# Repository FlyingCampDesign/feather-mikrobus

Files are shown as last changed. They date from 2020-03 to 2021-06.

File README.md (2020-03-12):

# feather-mikrobus
A simple [Adafruit Feather](https://www.adafruit.com/feather) to [mikroBUS](https://www.mikroe.com/mikrobus) socket adapter board.

View this project on [CADLAB.io](https://cadlab.io/project/22579). 

## Hardware

Hardware source files for [KiCad](https://kicad-pcb.org/) are available in the `hardware/` directory.  For details on features and pinouts, see the individual `README.md` for each hardware version.

### Hacking

The KiCad source files depend on the [Flying Camp Design KiCad Library](https://github.com/FlyingCampDesign/fcd-kicad-lib) being available as a git submodule.  The easiest way to ensure that all dependencies are available is to clone this repository using the following command:

```bash
git clone --recurse-submodules https://github.com/FlyingCampDesign/feather-mikrobus.git
```

To ensure that the 3D model paths are configured correctly for the 3D viewer, make sure to follow the FCD library [usage instructions](https://github.com/FlyingCampDesign/fcd-kicad-lib#usage) (otherwise, none of the 3D models will show up).

### [Feather mikroBUS V1](hardware/feather-mikrobus-v1/)

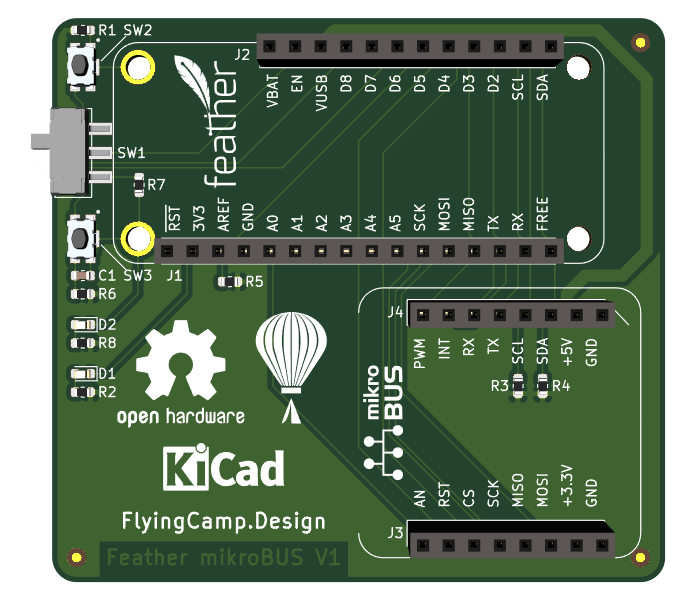
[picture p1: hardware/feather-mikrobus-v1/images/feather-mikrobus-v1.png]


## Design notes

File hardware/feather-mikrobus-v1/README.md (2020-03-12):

# Feather mikroBUS V1



## Features

* Power On/Off switch
* +3.3V power indicator LED
* User button
* User LED
* Bootloader enable (BOOT0) button for [Adafruit Feather STM32F405 Express](https://www.adafruit.com/product/4382)

## Pinout

| Feather Pin Name | mikroBUS Pin Name | FeatherWing Function |
| --- | --- | --- |
| RESET | | (not used) |
| 3V3 | +3.3V | +3.3V |
| AREF | | Connected to +3.3V via 0Ω jumper R5 |
| GND | GND | GND |
| A0 | AN | |
| A1 | | (not used) |
| A2 | | (not used) |
| A3 | | (not used) |
| A4 | | (not used) |
| A5 | | (not used) |
| SCK | SCK | |
| MOSI | MOSI | |
| MISO | MISO | |
| TX | RX | |
| RX | TX | |
| FREE | | Connected to BOOT0 button SW2 for [Adafruit Feather STM32F405 Express](https://www.adafruit.com/product/4382) |
| SCL | SCL | |
| SDA | SDA | |
| D2 | INT | |
| D3 | PWM | |
| D4 | RST | |
| D5 | | Connected to user LED D1 (active low) |
| D6 | | Connected to user button SW3 (active low) |
| D7 | CS | |
| D8 | | (not used) |
| VUSB | +5V | +5V |
| EN | | Controlled by SW1 |
| VBAT | | (not used) |

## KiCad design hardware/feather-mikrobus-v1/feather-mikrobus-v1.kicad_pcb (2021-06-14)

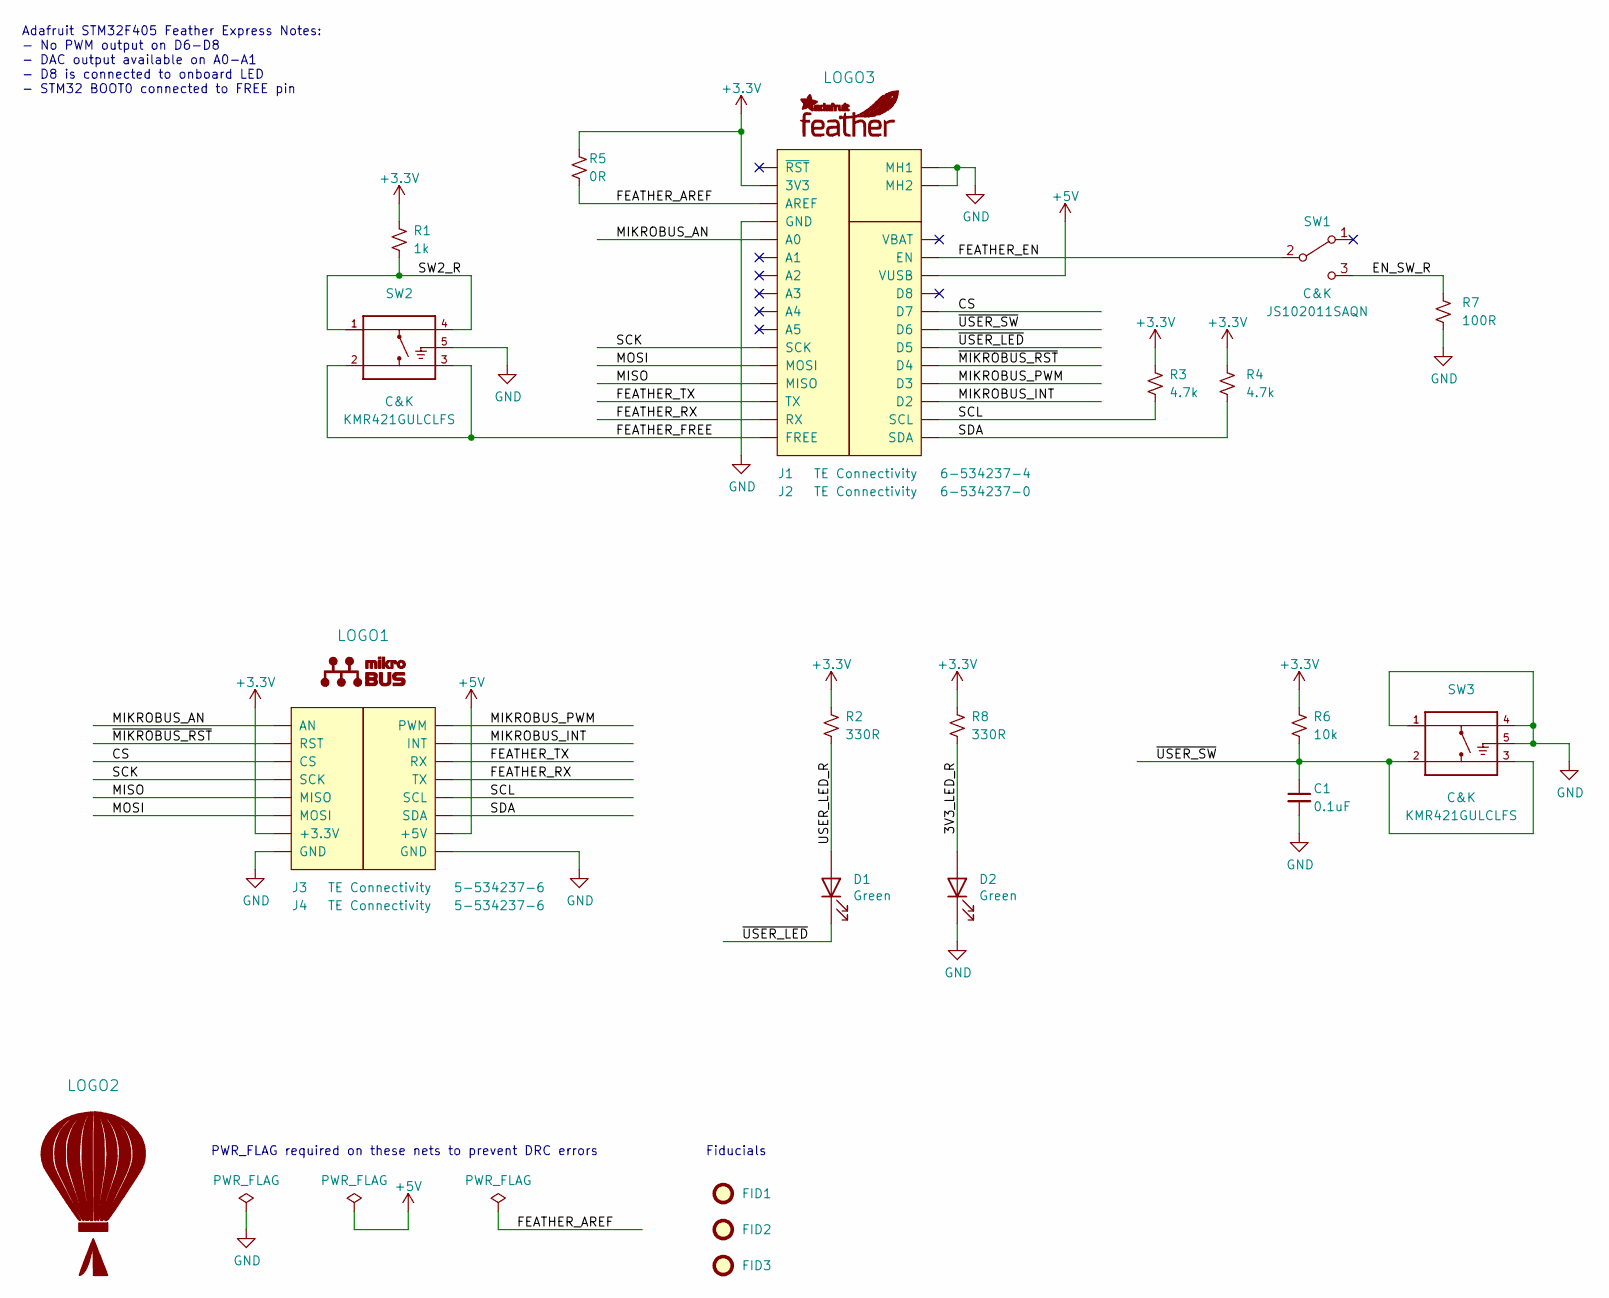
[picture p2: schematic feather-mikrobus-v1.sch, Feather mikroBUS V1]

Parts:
C1: Murata_GRM188R72A104KA35D; C_0603_1608Metric; Manufacturer Part Number GRM188R72A104KA35D
D1, D2: Lite-On_LTST-C193KGKT-5A; LED_0603_1608Metric; Manufacturer Part Number LTST-C193KGKT-5A
FID1, FID2, FID3: Fiducial_1mm_Mask2mm
J1: Adafruit_Feather_socket_header_left_pth; Manufacturer Part Number 6-534237-4
J2: Adafruit_Feather_socket_header_right_pth; Manufacturer Part Number 6-534237-0
J3: mikroBUS_socket_header_left_pth; Manufacturer Part Number 5-534237-6
J4: mikroBUS_socket_header_right_pth; Manufacturer Part Number 5-534237-6
LOGO1: mikroBUS-Logo_11.9x4.1mm_SilkScreen
LOGO2: Flying_Camp_Design_logo_7.35x11mm_silkscreen
LOGO3: Adafruit_Feather_logo_13.87x6.33mm_silkscreen
MH1: Adafruit_Feather_socket_mounting_holes
R1: Yageo_RC0603JR-071KL; R_0603_1608Metric; Manufacturer Part Number RC0603JR-071KL
R2, R8: Yageo_RC0603JR-07330RL; R_0603_1608Metric; Manufacturer Part Number RC0603JR-07330RL
R3, R4: Yageo_RC0603JR-074K7L; R_0603_1608Metric; Manufacturer Part Number RC0603JR-074K7L
R5: Yageo_RC0603JR-070RL; R_0603_1608Metric; Manufacturer Part Number RC0603JR-070RL
R6: Yageo_RC0603JR-0710KL; R_0603_1608Metric; Manufacturer Part Number RC0603JR-0710KL
R7: Yageo_RC0603JR-07100RL; R_0603_1608Metric; Manufacturer Part Number RC0603JR-07100RL
SW1: C_and_K_JS102011SAQN; Manufacturer Part Number JS102011SAQN
SW2, SW3: C_and_K_KMR421GULCLFS; Manufacturer Part Number KMR421GULCLFS

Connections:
+3V3: J1.3V3, J3.+3.3V, R1.1, R2.1, R3.1, R4.1, R5.1, R6.1, R8.1
+5V: J2.VUSB, J4.+5V
/3V3_LED_R: D2.2 (A), R8.2
/CS: J2.D7, J3.CS
/EN_SW_R: R7.1, SW1.3 (C)
/FEATHER_AREF: J1.AREF, R5.2
/FEATHER_EN: J2.EN, SW1.2 (B)
/FEATHER_FREE: J1.FREE, SW2.2, SW2.3
/FEATHER_RX: J1.RX, J4.TX
/FEATHER_TX: J1.TX, J4.RX
/MIKROBUS_AN: J1.A0, J3.AN
/MIKROBUS_INT: J2.D2, J4.INT
/MIKROBUS_PWM: J2.D3, J4.PWM
/MISO: J1.MISO, J3.MISO
/MOSI: J1.MOSI, J3.MOSI
/SCK: J1.SCK, J3.SCK
/SCL: J2.SCL, J4.SCL, R3.2
/SDA: J2.SDA, J4.SDA, R4.2
/SW2_R: R1.2, SW2.1, SW2.4
/USER_LED_R: D1.2 (A), R2.2
/~MIKROBUS_RST: J2.D4, J3.RST
/~USER_LED: D1.1 (K), J2.D5
/~USER_SW: C1.1, J2.D6, R6.2, SW3.2, SW3.3
GND: C1.2, D2.1 (K), J1.GND, J3.GND, J4.GND, MH1.MH1, MH1.MH2, R7.2, SW2.5 (G), SW3.1, SW3.4, SW3.5 (G)

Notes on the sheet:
Adafruit STM32F405 Feather Express Notes: - No PWM output on D6-D8 - DAC output available on A0-A1 - D8 is connected to onboard LED - STM32 BOOT0 connected to FREE pin
PWR_FLAG required on these nets to prevent DRC errors
Fiducials

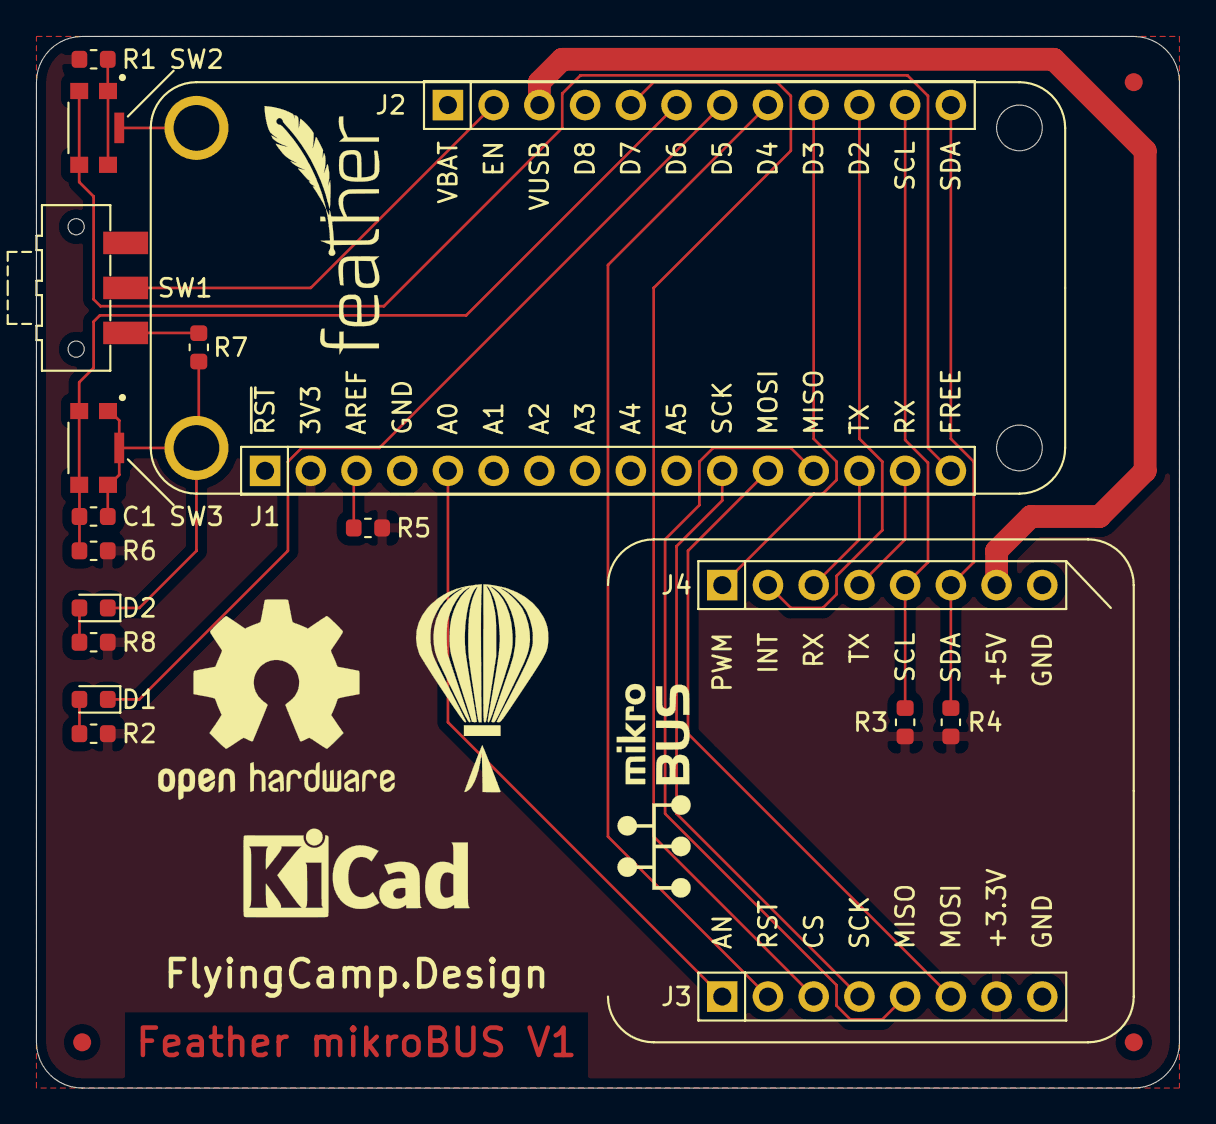
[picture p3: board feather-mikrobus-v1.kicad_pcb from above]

Board: 2 copper layers, 63.5 x 58.4 mm, 25 parts (0 on the bottom side), 24 nets.

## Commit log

2020-02-10 WIP: add initial design files
    [feather-mikrobus.kicad_pcb, feather-mikrobus.sch]
2020-02-11 Change names
    [feather-mikrobus.kicad_pcb, feather-mikrobus.sch]
2020-02-12 Finish schematic and board routing for V1
    [feather-mikrobus.kicad_pcb, feather-mikrobus.sch]
2020-02-12 Minor cosmetic updates to drawings
    [feather-mikrobus.kicad_pcb, feather-mikrobus.sch]
2020-02-12 Move KiCad design into hardware subdirectory
    [feather-mikrobus.kicad_pcb, feather-mikrobus.sch]
2020-02-12 Add version to KiCad file names
    [feather-mikrobus-v1.kicad_pcb, feather-mikrobus-v1.sch]
2020-02-12 Add version to drawing frame title
    [feather-mikrobus-v1.kicad_pcb, feather-mikrobus-v1.sch]
2020-02-24 Update symbols and minor cleanup
    [feather-mikrobus-v1.kicad_pcb, feather-mikrobus-v1.sch]
2020-03-08 Update fcd-kicad-lib submodule
2020-03-08 Remove dependencies on KISYS3DMOD
    [feather-mikrobus-v1.kicad_pcb]
2020-03-08 Clean up PCB file
    [feather-mikrobus-v1.kicad_pcb]
2020-03-10 Update schematic with finalized manufacturers and vendors
    [feather-mikrobus-v1.sch]
2020-03-10 Import latest netlist into PCB
    [feather-mikrobus-v1.kicad_pcb]
2020-03-10 Update sheet fields
    [feather-mikrobus-v1.kicad_pcb, feather-mikrobus-v1.sch]
2020-03-11 Update schematic to use new symbols and worksheet
    [feather-mikrobus-v1.sch]
2020-03-11 Add Flying Camp Design logo
    [feather-mikrobus-v1.kicad_pcb, feather-mikrobus-v1.sch]
2020-03-11 Add Flying Camp Design logos
    [feather-mikrobus-v1.kicad_pcb, feather-mikrobus-v1.sch]
2020-03-11 Remove dependencies on global libraries
    [feather-mikrobus-v1.sch]
2020-03-14 Change LICENSE to CERN-OHL-P
    [feather-mikrobus-v1.kicad_pcb, feather-mikrobus-v1.sch]
2021-02-27 Upgrade design to KiCad 5.99
    [feather-mikrobus-v1.kicad_pcb, feather-mikrobus-v1.kicad_sch, feather-mikrobus-v1.sch]
2021-03-01 Update design to KiCad 6 formats
2021-03-01 Remove Adafruit star from Feather logo
    [feather-mikrobus-v1.kicad_pcb, feather-mikrobus-v1.kicad_sch]
2021-03-01 Update KiCad URL
2021-06-14 Revert "Update KiCad URL"
    This reverts commit 2d5a2093c9c00809c1c9f870612bf2622a1c6c3e.
2021-06-14 Revert "Remove Adafruit star from Feather logo"
    This reverts commit b8ad0b09bffcc386ca4397281ed953137447e20d.
    [feather-mikrobus-v1.kicad_pcb, feather-mikrobus-v1.kicad_sch]
2021-06-14 Revert "Update design to KiCad 6 formats"
    This reverts commit e90d167ee0dfb78906e166fe0c4b3ad904510116.
2021-06-14 Revert "Upgrade design to KiCad 5.99"
    This reverts commit 404d8fe5192a3f2d218e68c3ca65a2b30fdaee8b.
    [feather-mikrobus-v1.kicad_pcb, feather-mikrobus-v1.kicad_sch, feather-mikrobus-v1.sch]

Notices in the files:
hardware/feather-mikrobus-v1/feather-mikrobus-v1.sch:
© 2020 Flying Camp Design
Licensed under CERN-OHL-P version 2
